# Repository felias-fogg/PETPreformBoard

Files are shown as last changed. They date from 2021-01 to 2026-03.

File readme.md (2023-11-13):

# The PET Preform Board

The **PET Preform Board** board is a small PCB (67.8 x 15.6 mm) intended to be placed into a preform tube (with length of > 13cm) together with a 3.6 volt Lithium battery. On the board, you can place an ATtiny1634 and a dot matrix 5x7 display as well as some sensor breakout board (such as the popular GY boards). Meanwhile we have reached version *V4a* of the board design. In order to give an idea, here is a photo of this board in a preform tube.

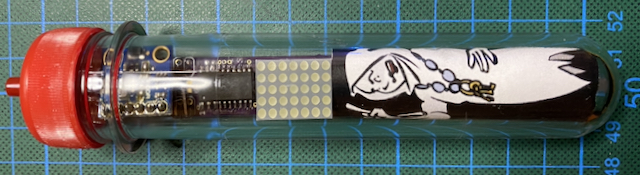
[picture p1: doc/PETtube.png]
PETling photo


With a barometer, you can, for example, ask people to take the tube and carry it up to the summit of a hill. At the summit, the display then reavals a code. An example for this usage is the [geocache at Dagstuhl castle](https://coord.info/GC4XBM2).

You'll find the Eagle files in the subdirectory *doc/eagle* together with pictures of how the PCB looks like. Let us now have a look at the top side.

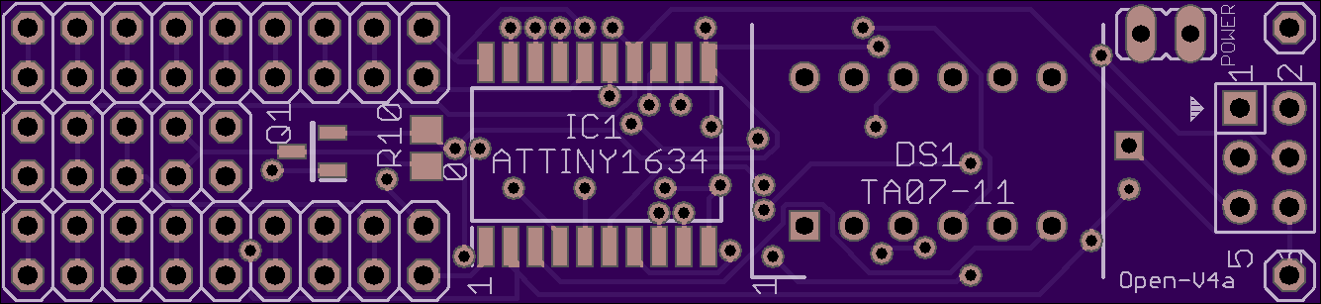
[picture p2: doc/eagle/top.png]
Top of PCB


On the right side, there is an ICSP header that one can use for programmig. Close to the ICSP header on the top, there is a 2-pin header for a power jumper. Without the jumper, the battery is cut off from the board. Then comes left of the ICSP header the place for the dot matrix display **DS1**, e.g., ***TA07-11SEKWA***. It is adivsable to chose a hyper-orange or hyper-red type because we can spare only a few mill Amps to light the dots. Even further left is the space for **IC1**, the MCU ***ATtiny1634***. Both the dot matrix display and the MCU have their respective 1-pins at the bottom to the left, as marked with the "1".

Left of the MCU, there is space for the *optional* resistor **R10** of 0Ω. Put that in if you want to connect the Vcc pin of a sensor directly to the battery. If you want to switch the power to the sensor, put instead the *optinonal* P-channel MOS-FET ***IRLML2244*** at the place marked Q1. 

Let us now look at the bottom of the board.
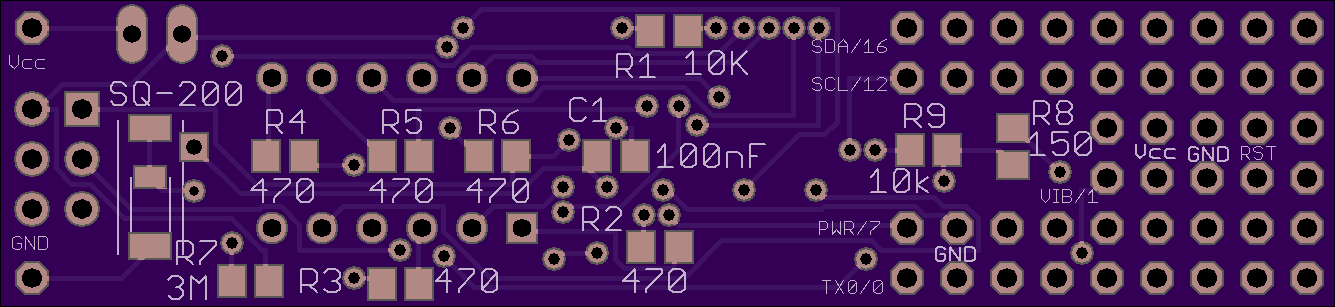
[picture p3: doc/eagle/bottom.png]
Bottom of PCB


Now we start from the left, where we see the bottom of the ICSP header. Then there are SMD pads for an *optional* ***SQ-MIN-200*** or ***SQ-SEN-200*** vibration sensor. These are extremely sensitive, but also a bit expensive. Directly right to the pads are two through-hole pads that can be used for an alternative ***SW-18010*** vibration sensor, which is less expensive but also less sensitive.

The resistor **R7** is the pull-up for the vibration switch. The SW-18010 is usually open, but the SQ-xxx-200 switch is usually closed. So, 3MΩ seems to be a good value, limiting the quiescent current to roughly 1.2 µA. Currently, I use 10MΩ, which still works fine and saves even more power. The resistors **R2**-**R6** are current limiting resistors for the dot matrix display columns. I have labled them with 470Ω, but you also can use 330Ω or a lower value. You get a brighter display, but consume more power.  **R1** (10kΩ) is the usual pullup for the reset line and **C1** (100nF) is the blocking capacitor for the MCU. 

**R9** (10kΩ) is the pull-up for the MOSFET gate and **R8** (150Ω) is the current limiting resistor for the MOSFET. These two are, of course only necessary if one uses the MOSFET.

If you want to drive the sensor directly from the MCU pin, then **R8** should be 0Ω and you need to put another such bridge from the gate pad to the drain pad of the MOSFET.

Out of the 17 I/O lines of the ATtiny1634, 12 are used for the dot matrix display, one line is used for the vibration switch, two lines are dedicated for I2C, but could be used for other pusposes, one line is intended to be used for switching the MOSFET, and one line can be used as a TX line for debug outputs or it can be used for any other purpose. The pin assignment is described in the following table.

| MCU pin | MCU function | Arduino pin | Function | Display pin |
| ---:| :---| ---:|:---| ---:|
| 1 |TX0/PB0/ADC5  | A5/0 | TX/GPIO  | |
| 2 |RX0/PA7/PCINT7| A4/1 | Vib/GPIO | |
| 3 | PA6 | 2 | Row 7 | 6 |
| 4 | PA5 | 3 | Row 6 | 5 | 
| 5 | PA4 | 4 | Row 5 | 4 |
| 6 | PA3 | 5 | Row 3 | 2 |
| 7 | PA2 | 6 | Column 2 | 3 |
| 8 | PA1 | 7 |Power/GPIO| |
| 9 | PA0 | 8 | Column 1 | 1 |
| 10 | GND | | GND | |
| 11 | Vcc | | Vcc | |
| 12 | PC5 | 9 | Column 5 | 8 |
| 13 | PC4 | 10 | Column 4 | 7 |
| 14 | RESET | | | |
| 15 | PC2 | 11 | Row 1 | 12 |
| 16 | PC1/SCK/SCL  | A10/12| ICSP/I2C/GPIO | |
| 17 | PC0 | 13 | Row 2 | 11 |
| 18 | PB3 | 14 | Row 4 | 9 |
| 19 | PB2/MISO | 15 | ICSP/Column 3 | 10 |
| 20 | PB1/MOSI/SDA | A6/16 | ICSP/I2C/GPIO | |

An include file for the current version of the board is **PETPreformBoard.h** in the *src* direct

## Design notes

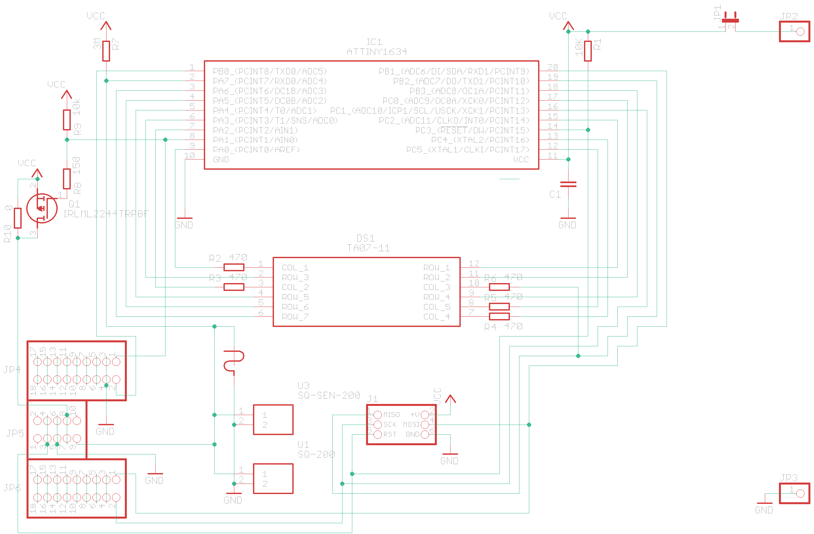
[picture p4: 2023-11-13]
doc/eagle/schema.png

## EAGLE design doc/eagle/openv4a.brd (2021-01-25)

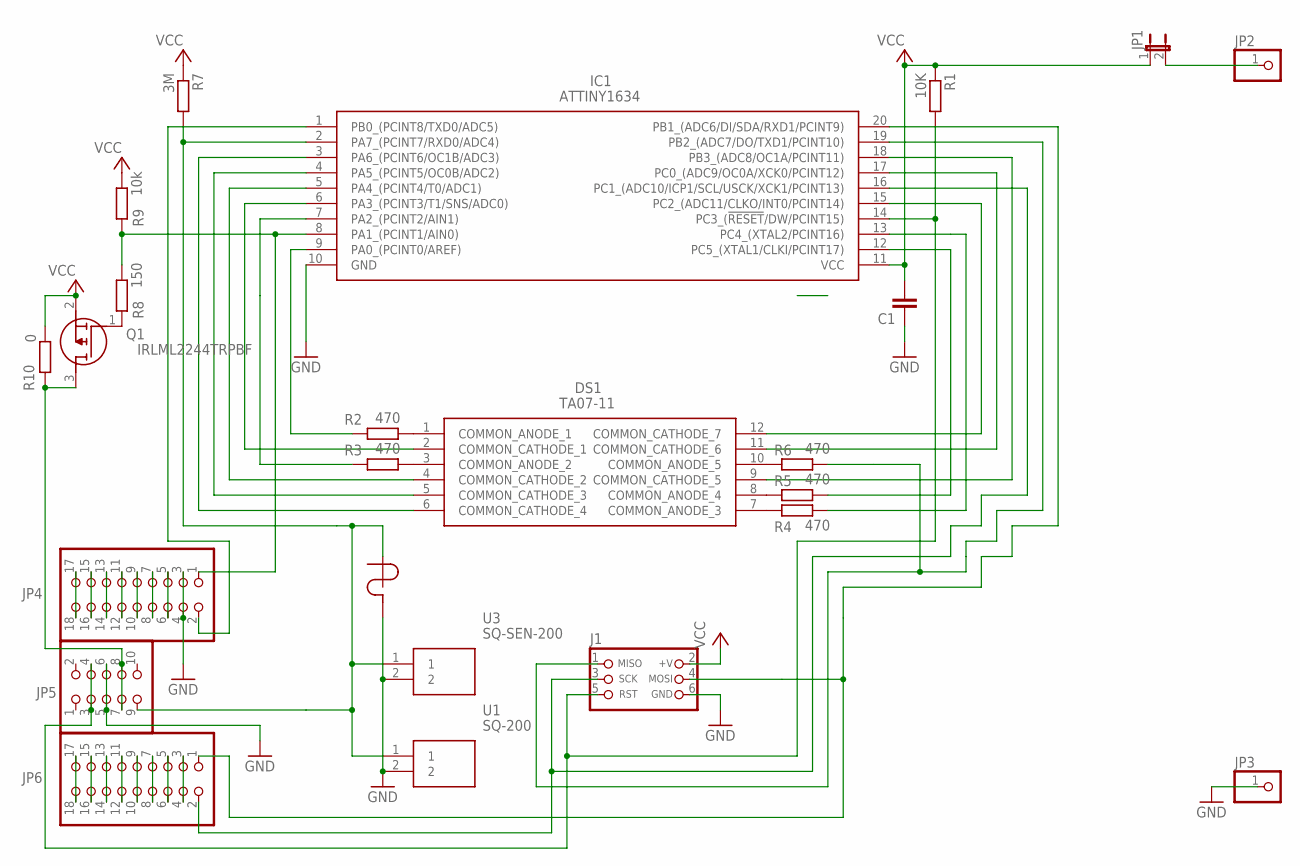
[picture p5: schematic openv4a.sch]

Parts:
C1: 100nF; C0805
DS1: TA07-11; DIPS762W75P254L1778H665Q12N; MANUFACTURER_PART_NUMBER TA07-11
IC1: ATTINY1634; SOIC127P1032X265-20N
J1: CON_HEADER_PRG_AVR_ICSP-PTH; HEADER_PRG_2X03
JP1: JP1E; JP1
JP2, JP3: PINHD-1X1; 1X01
JP4, JP6: PINHD-2X9; 2X09
JP5: PINHD-2X5; 2X05
Q1: IRLML2244TRPBF; SOT95P237X112-3N
R1: 10K; R0805
R2, R3, R4, R5, R6: 470; R0805
R7: 3M; R0805
R8: 150; R0805
R9: 10k; R0805
R10: 0; R0805
U1: SQ-200; SQMIN200
U2: VIB-SENS; SW-18010P
U3: SQ-SEN-200; SQSEN200

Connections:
GND: C1.1, IC1.10 (GND), J1.6 (GND), JP3.1, JP4.3, JP4.4, JP5.5, JP5.6, U1.2, U2.1, U3.2
unnamed: IC1.1 (PB0_(PCINT8/TXD0/ADC5)), JP4.2
unnamed: JP1.2, JP2.1
unnamed: DS1.1 (COMMON_ANODE_1), R2.2
unnamed: DS1.3 (COMMON_ANODE_2), R3.2
unnamed: DS1.7 (COMMON_ANODE_3), R4.1
unnamed: DS1.8 (COMMON_ANODE_4), R5.1
unnamed: DS1.10 (COMMON_ANODE_5), R6.1
unnamed: IC1.9 (PA0_(PCINT0/AREF)), R2.1
unnamed: IC1.8 (PA1_(PCINT1/AIN0)), JP4.1, R8.2, R9.1
unnamed: IC1.7 (PA2_(PCINT2/AIN1)), R3.1
unnamed: IC1.12 (PC5_(XTAL1/CLKI/PCINT17)), R5.2
unnamed: IC1.13 (PC4_(XTAL2/PCINT16)), R4.2
unnamed: DS1.2 (COMMON_CATHODE_1), IC1.6 (PA3_(PCINT3/T1/SNS/ADC0))
unnamed: DS1.4 (COMMON_CATHODE_2), IC1.5 (PA4_(PCINT4/T0/ADC1))
unnamed: DS1.5 (COMMON_CATHODE_3), IC1.4 (PA5_(PCINT5/OC0B/ADC2))
unnamed: DS1.6 (COMMON_CATHODE_4), IC1.3 (PA6_(PCINT6/OC1B/ADC3))
unnamed: IC1.19 (PB2_(ADC7/DO/TXD1/PCINT10)), J1.1 (MISO), R6.2
unnamed: JP4.5, JP4.6
unnamed: JP4.7, JP4.8
unnamed: JP4.9, JP4.10
unnamed: JP4.11, JP4.12
unnamed: JP4.13, JP4.14
unnamed: JP4.15, JP4.16
unnamed: JP4.17, JP4.18
unnamed: JP6.3, JP6.4
unnamed: JP6.5, JP6.6
unnamed: JP6.7, JP6.8
unnamed: JP6.9, JP6.10
unnamed: JP6.11, JP6.12
unnamed: JP6.13, JP6.14
unnamed: JP6.15, JP6.16
unnamed: JP6.17, JP6.18
unnamed: DS1.12 (COMMON_CATHODE_7), IC1.15 (PC2_(ADC11/CLKO/INT0/PCINT14))
unnamed: DS1.11 (COMMON_CATHODE_6), IC1.17 (PC0_(ADC9/OC0A/XCK0/PCINT12))
unnamed: IC1.16 (PC1_(ADC10/ICP1/SCL/USCK/XCK1/PCINT13)), J1.3 (SCK), JP6.2
unnamed: Q1.1 (G), R8.1
unnamed: IC1.20 (PB1_(ADC6/DI/SDA/RXD1/PCINT9)), J1.4 (MOSI), JP6.1
unnamed: DS1.9 (COMMON_CATHODE_5), IC1.18 (PB3_(ADC8/OC1A/PCINT11))
unnamed: IC1.2 (PA7_(PCINT7/RXD0/ADC4)), JP5.9, R7.2, U1.1, U2.2, U3.1
unnamed: IC1.14 (PC3_(!RESET!/DW/PCINT15)), J1.5 (RST), JP5.3, JP5.4, R1.2
unnamed: JP5.7, JP5.8, Q1.3 (D), R10.2
VCC: C1.2, IC1.11 (VCC), J1.2 (+V), JP1.1, Q1.2 (S), R1.1, R7.1, R9.2, R10.1

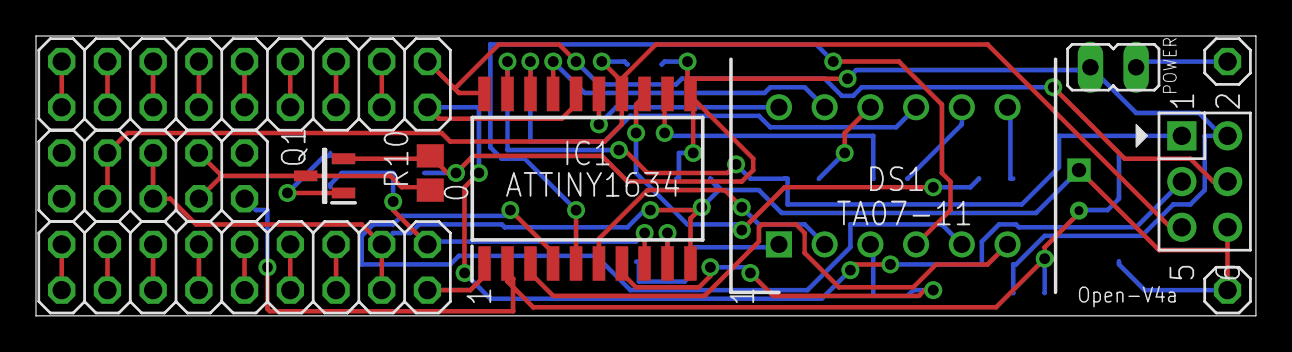
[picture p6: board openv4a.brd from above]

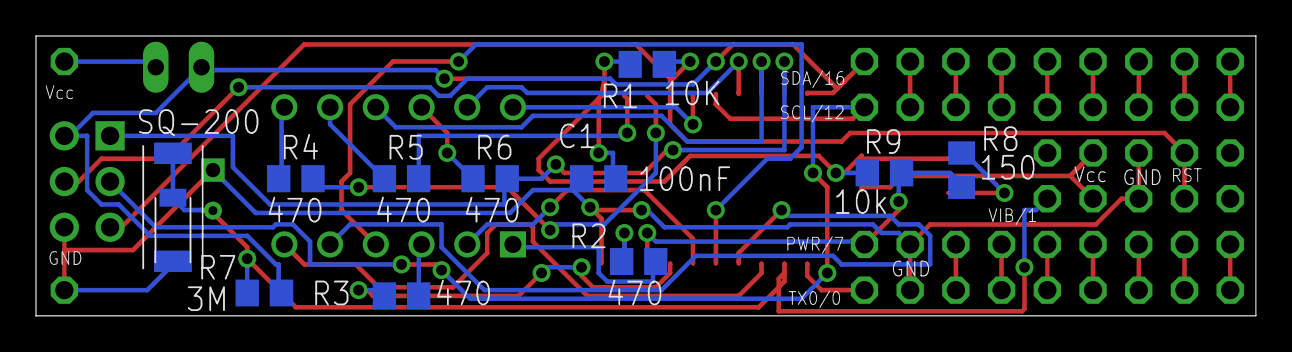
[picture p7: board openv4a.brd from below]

Board: 2 copper layers, 67.8 x 15.5 mm, 24 parts (13 on the bottom side), 43 nets.

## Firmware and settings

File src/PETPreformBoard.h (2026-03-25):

// maps the port for the "upAndDown" sketches pins according to the MCU type

#ifndef PETPREFORMBOARD_H
#define PETPREFORMBOARD_H

#ifndef PPB_VERSION4
#define PPB_VERSION4 'A'
#endif

#if (PPB_VERSION4 != 'A') && (PPB_VERSION4 != '0')
#error "Illegal PETPreformBoard version number: " PPB_VERSION4
#endif

#define __AVR_ATtiny1634__ 1

#if defined(__AVR_ATmega328P__)
#define DMCOL1 2
#define DMCOL2 3
#define DMCOL3 4
#define DMCOL4 5
#define DMCOL5 6
#define DMROW1 7
#define DMROW2 8
#define DMROW3 9
#define DMROW4 10
#define DMROW5 11
#define DMROW6 12
#define DMROW7 13
#define SDA_PORT PORTC
#define SDA_PIN 4 // Arduino pin A4/18
#define SDA 18
#define SCL_PORT PORTC
#define SCL_PIN 5 // Arduino pin A5/19
#define SCL 19
#define POWER 14 // (A0)
#define VIB_IF PCIFR
#define VIB_PCIF PCIF1
#define VIB_PCINT PCINT9 // 15
#define VIB_MASK PCMSK1
#define VIB_PCIE PCIE1
#define VIB_PCICR PCICR
#define VIB_PCINT_vect PCINT1_vect
#define TX 1
#define SIM_RESET 15 // (A1) press to simulate a manual reset (while pressing RESET)
#define SIM_POR 16 // (A2) press to simulate power on reset  (while pressing RESET)
#elif defined (__AVR_ATtiny1634__)
#define DMCOL1 8
#define DMCOL2 6
#define DMCOL3 15
#define DMCOL4 10
#define DMCOL5 9
#define DMROW1 11
#define DMROW2 13
#define DMROW3 5
#define DMROW4 14
#define DMROW5 4
#define DMROW6 3
#define DMROW7 2
#define SDA_PORT PORTB
#define SDA_PIN 1 // Arduino pin 16
#define SDA 16
#define SCL_PORT PORTC
#define SCL_PIN 1 // Arduino pin 12
#define SCL 12
#define POWER 7
#define VIB_IF GIFR
#define VIB_PCIF PCIF0
#define VIB_PCINT PCINT7 // 1
#define VIB_MASK PCMSK0
#define VIB_PCIE PCIE0
#define VIB_PCICR GIMSK
#define VIB_PCINT_vect PCINT0_vect
#define OSCCAL OSCCAL0
#define TX 0
#if PPB_VERSION4 == '0' // First version of board OPEN-V4
#undef DMCOL2
#define DMCOL2 16
#undef DMCOL3
#define DMCOL3 6
#undef SDA_PIN
#define SDA_PIN 2
#undef SDA
#define SDA 15
#endif 
#else
#error "MCU type is not supported"
#endif

#endif

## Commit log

2023-11-13 fixed typos and added schematic
2023-11-13 added schematic
